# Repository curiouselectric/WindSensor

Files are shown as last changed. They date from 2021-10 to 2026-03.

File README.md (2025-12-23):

# WindSensor Overview
A DIY Wind sensor interface board.

This connects to various anemometers and wind vanes and provides a serial interface for averaged data from the pulses.

The problem with measuring wind anemometers and wind vane is that they constantly need to be checked. You need to know at all times when pulses have come in and which direction the wind vane is facing. This requires a bit of microcontroller time and processing. This unit is designed to solve that.
Wire up your vane and anemometer. Power the unit up. Then it will save the averaged data for you. You can then get hold of the data through serial requests and process as you need.

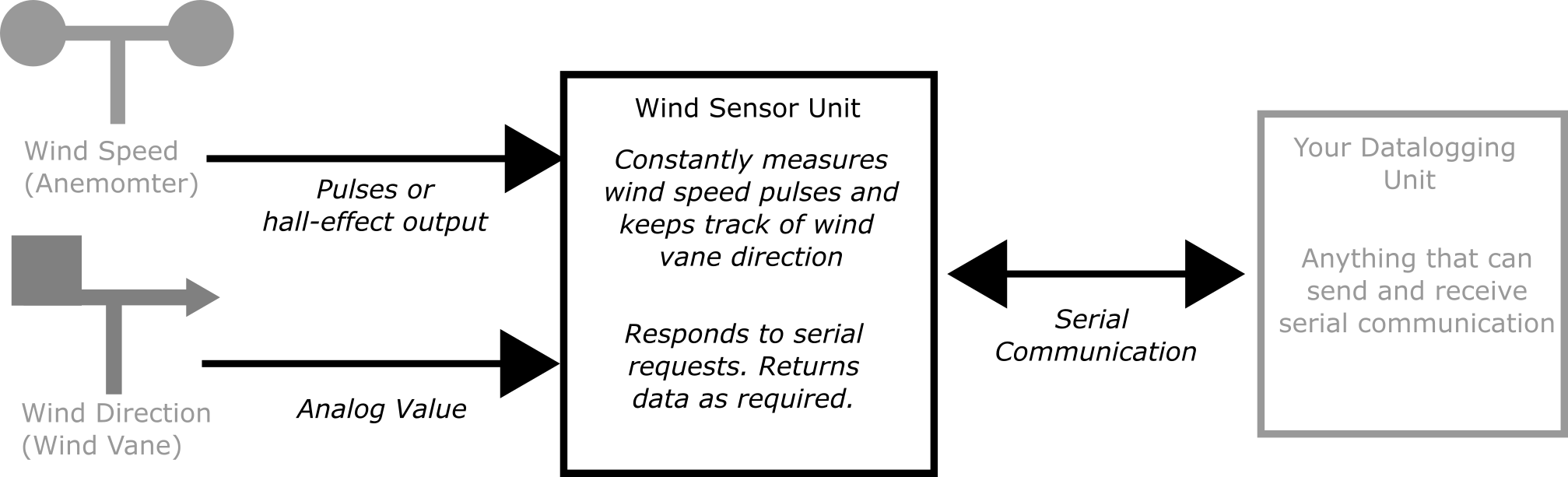
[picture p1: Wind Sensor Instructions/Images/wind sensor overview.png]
Overview


I wrote this to interface to an ESP32 data logger, which sleeps most of the time. It wakes up, talks to the wind sensor, gets the data it needs, then goes back to sleep, knowing the wind sensor is always monitoring.

It was designed as a relatively simple interface to remove the need for monitoring pulses and averaging them. 

## Wind Speed Measurements

The anemometer can either be a pulse output, NPN output or hall-effect output. The unit reads digital pulses, with circuitry on the unit converting the hall effect output to pulses. (Note: This unit cannot read 0-5V or analog output sensors).

The unit stores average wind speeds for 1 second, 10 second, 1 min, 10 min and 1 hour values. It also records the maximum and minimum wind speed.

The unit converts the pulses into a real wind speed using a y=mx+c linear conversion, where y is the wind speed and c is the number of pulses. m and c are stored in EEPROM and have default values of m=1 and c=0. These are floats and can be changed as required through the serial interface. Any updated values are stored in EEPROM. If the pulses are zero then the output is also zero (no matter what the y=mc+c function is). This stops a reading of 'c' when the pulse data is zero.

## Wind Vane Measurements

The wind vane input is analog. 

This can read either resistive wiper vanes or stepped resistive vanes. 

The stepped rsistive vanes have magnet reed switches which switch in and out different resistances. 
The resistance then tells us the direction. A pull up reistor is required in these situations.

The wind vane input can be 'trained'. So put the unit into vane training mode via the serial interface. This will run through N, NE, E, SE, S, SW, W, NW and you can hold the unit in the correct direction position and press the switch to store that data to memory. Once trained then the unit creates a buffer zone around each of the values and within the zone then the unit will record the correct direction.

Wind direction is difficult to measure, as you cannot directly average the analog value (because of the 360 to 0 point where the analog value rolls around from 1024 back to 0 - this means an average of a unit pointing just off north (i.e. one reading of 0 and one reading of 360) will give an average of (360+0)/2 = 180, which is south and totally wrong!). 

This unit will record the number of seconds the vane has been pointing in a certain direction. This means a 'wind rose' can easily be created. This is stored and updated until it is directly reset. The unit will also return the instantaeous direction, if that is needed.

Note: there is a 3V3 zener diode on the input to the Wind Vane unit. If you power the device with 3.3V then this is no problem. If you power the device with 5V then you will need to ensure the voltage at VANE does not go above 3.3V or else it will be limited.

There are two mode of operation, depending upon your use case:

## Response Mode

In this mode then the unit responds to serial requests made. You ask the sensor for data and this is returned. It never sends anything unless asked. 

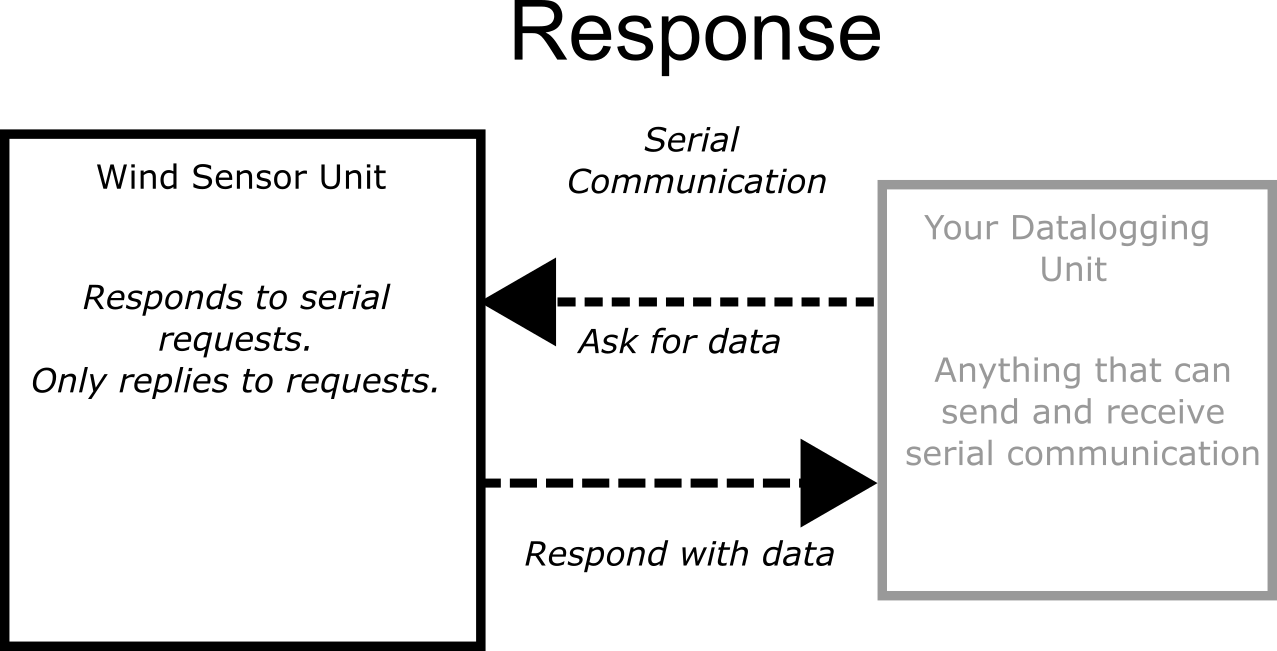
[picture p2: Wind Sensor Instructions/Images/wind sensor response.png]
Response


## Broadcast Mode

In this mode then the unit regularly sends data via the serial connunication. It will send the averaged data for (0) 1 second, (1) 10 second, (2) 1 min, (3) 10 min and (4) 1 hour averaged data. If this is set to (5) then the unit does not send any data. The send mdoe is stored in EEPROM, so it will start sending data again even if power is lost.

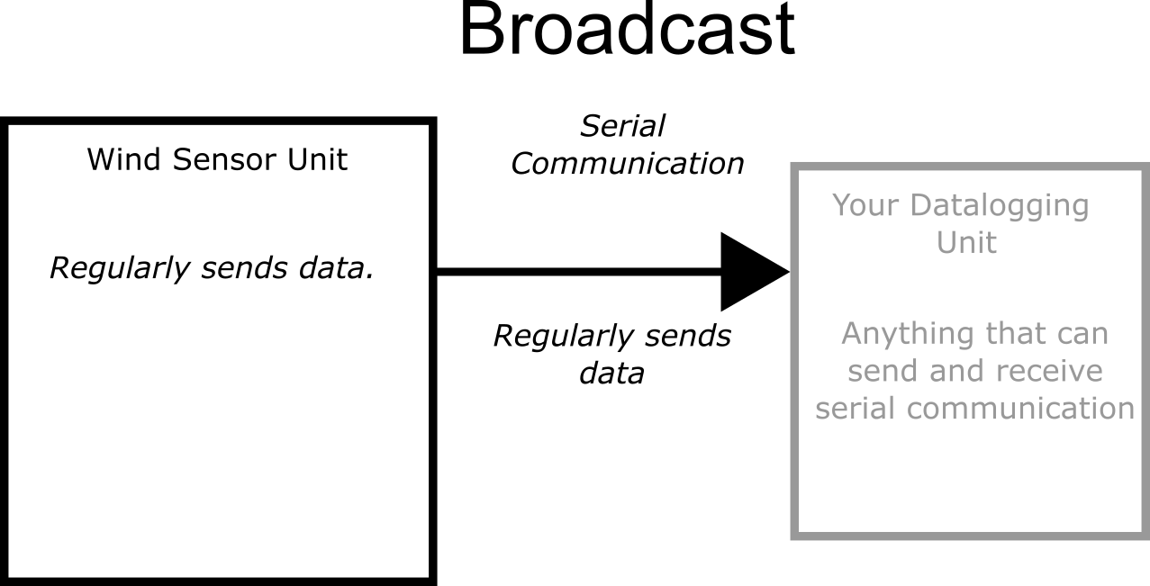
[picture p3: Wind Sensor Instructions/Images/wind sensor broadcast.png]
Broadcast


Boradcast mode works well if the logger is always listening and you only have one sensor in range. If more than one sensor is in range then the data will clash and potentially cause issues, in which case use Response mode.

The two modes work together - you can have the unit sending regular data and also responding to requests.

It runs on an ATMega328 running at 8MHz with selectable baud serial (up to 57600). It comes pre-programmed, but code can be uploaded via the Arduino IDE, using the MiniCore board add-on. See firmware for more details.

# Hardware

The PCB was designed in KiCAD and is available here. A small PCB has been designed.
There is one reset switch, one user input switch and one LED output.

Both inputs for the wind vane and anemometer are buffered with an op-amp and also have 5.1V zener protection. The anemometer input compares the input with a low voltage level to create a pulse from a hall-effect (which output a sine-wave like signal). This also works as a pull-down pulse sensor, which works with NPN and switch output anemometers.

## Anemometers Tested:

Anemometer Name      | Link   | Type   | m Value   | c Value
---------------------|----------|---------|----------|----------
Vector Insrutments NRG #40C | https://www.nrgsystems.com/products/met-sensors/detail/40c-anemometer | Hall-effect  | 0.765 for m/s | 0.35 for m/s
Maplin Anemometer (low cost) | https://www.ebay.co.uk/itm/274338314354 | Reed-switch pulse | 0.7 for m/s | 0 for m/s
AliExpress Unit (low cost) PR-3000-FS-NPN| https://www.aliexpress.com/item/32798148991.html | NPN Pulse | |

## Wind Vanes Tested:

Wind Vane Name      |   Link   |  Type
---------------------|----------|-----------
Maplin Vane | No Link |  Switched resistive

## Board ID Number

Each unit can have a unique ID (using a solder pad for 0-7 values), so multiple units can be added to a serial bus, if needed. The defalt is 0.

## PCB User Switch and User LED

There is one user switch and one user LED on the unit.

The LED will show a regular flash every 5 seconds. This will briefly flash once every 5 seconds if the unit is in 'Response' mode. The LED will briefyl flash twice every 5 seconds if the unit is in 'Broadcast' mode. Data will be sent at the broadcast rate.

The LED will also flash whenever data is sent of the serial port. The LED will go on before data sent and then off after data is sent.

Pressing the user switch for >0.5 seconds and then releasing will result in a switch press. 

A switch press will increment the mode from 0-1-2-3-4-5 then back to 0. 

The unit will flash after a button press to indicate the broadcast mode (so 0 flashes if the value is 0, 1 flash if the value is 1 etc). 

If this is set to 5 then the unit works in 'Response' mode. 

If this is set to 0-4 then the unit is in broadcast mode and will send the data at the relevant interval (0 = 1s, 1 = 10s, 2 = 1 min, 3 = 10 min and 4 = 1 hour). 

The mode can also be set with a serial request, using the "Set the unit to broadcast:" method (see below).

# Firmware
This uses an ATMega328 running at 8MHz with 3.3v or 5V supply.

## Initial bootloader installation:
You should not need to do this, as the unit should come with this already installed. This is just for information.

To upload a bootloader it then MiniCore is used:

Install MiniCore from here: https://github.com/MCUdude/MiniCore

Install the bootloader using an Arduino as an ISP. https://www.arduino.cc/en/Tutorial/BuiltInExamples/ArduinoISP

Wire up your arduino and an ISP 3x2 header pin onto the wind sensor PCB.

Choose the "ATMega328" option with the "External 8MHz Oscillator" set.

You can then use the 'Burn Bootloader' option within 'Tools' in the Arduino IDE. This will install the Minicore bootloader.

## Program via Arduino IDE

To program it then MiniCore is used:

Install MiniCore from here: https://github.com/MCUdude/MiniCore

Add to preferences and then board manager.

You can then upload code by choosing the "ATMega328" option with the "External 8MHz Oscillator" set.

# Serial Data and Commands

It returns the average values and information when requested on serial port.
At all other times then the unit is asleep.

## Wind Speed data:
Request: “aaI0WSA4#”  ("aaI0WSA4?19#" with CRC)  Where 0 is an ID from 0-7 set by solder on PCB. 4 is the averaging period (0=1s, 1=10s, 2 = 60s, 3 = 600s, 4=3600s)  

Returns: "aaI0WSA4:3.00:5.67:1.23#"  // Where 4 is the averaging period, 3.00 is the data within the averaging period, 5.67 is the maximum and 1.23 is the minimum. 
                                      
## Wind Speed data minimum:
Request: “aaI0WSMN#” ("aaI0WSMN?84#" with CRC) - does not matter what averaging period. min/max are just the min/max seen.

Returns: "aaI0WSMN:3.00#"  // Where 3.00 is the data + CRC if requested
                                      
## Wind Speed data maximum:
Request: “aaI0WSMX#”  ("aaI0WSMX?e6#" with CRC) - does not matter what averaging period. min/max are just the min/max seen.

Returns: "aaI0WSMX:3.00#"  // Where 3.00 is the data + CRC if requested

## What is Anemometer conversion?:    
Request: "aaI0WSCON#" ("aaI0WSCON?41#" with CRC)

Returns: "aaI0STWSCONm123.4c567.89#" (from stored values) + CRC if requested
                                      
## Set the Anemometer conversion:      
Request: "aaI0WSSTm123.4c567.89#"  ("aaI0WSSTm123.4c567.89?38#" with CRC) Where 123.4 is the gradient and 567.89 is the constant (y=mx+c)

Returns: "aaI0STWSSETm123.4c567.89#" (set to the new values) + CRC if requested

Request: "aaI0WSSTm1c0#" or "aaI0WSSTm1c0?da#" with CRC to set m= 1 and c=0. This is useful for initial testing.
                                      
## Wind Vane data: 
Request: “aaI0WV#”  ("aaI0WV?b4#" with CRC) Where 0 is an ID from 0-7 set by solder on PCB.

Returns:    The instantaneuous direction AND the direction array data
                                     
Returns:    "aaI0WV=W:0.00:0.00:0.00:0.00:0.00:0.00:62.00:0.00#" + CRC if requested
                                     
## Reset the max, min and wind vane array:  
Request: "aaI0RESET#" ("aaI0RESET?d9#" with CRC)

Returns: "aaRESET#"

## Set the unit to broadcast:  
Request: "aaI0SEND?#" where ? is an int (0)= 1s data, (1)= 10s data, (2)= 60s/1 min data, (3)= 600s/10 min data, (4)= 3600s/1hr data, (5)= NO data 

Returns: "aaI0SENDOK#" + CRC if requested

You can also set the unit to broadcast using the user switch. Press the button for around 0.5s or more then release. This will go through the boradcast modes from 0-1-2-3-4-5 then back round to 0. The LED will flash the number of times for the setting (so send = 0 the unit will not flash, but data will appear within 1 second!).

If the unit is in broadcast mode then the minimum and maximum wind speeds and the wind vane data are all reset each time period.

## What is baud rate?:                 
Request: "aaI0BD#" ("aaI0BD?dc#" with CRC)

Returns: "aaBD9600#"  // Where 9600 is the baud rate + CRC if requested
                                      
## Set Baud Rate:                      
Request: "aaI0STBD*#"  Where * is (0)1200, (1)2400, (2)9600, (3)57600, (4)115200

Returns: "aaBD9600#"   // Where 9600 is the baud rate + CRC if requested

## What is ID?:                        
Mentioned at start up of unit - it is solder-programmed... cannot be changed in code.

ID selection is by using a blob of solder to connect together some pads labelled A0, A1 and A2. The default is for no pads to be soldered and the ID is 0. This means the unit will respond to "I0" as the ID.

To change the ID to another number from 0-7 then we can solder the different connection pads to create a binay number. The connections are:

A0     |A1     |A2     | ID
-------|-------|-------|----
NC     |NC     |NC     | 0
Solder |NC     |NC     | 1
NC     |Solder |NC     | 2
Solder |Solder |NC     | 3
NC     |NC     |Solder | 4
Solder |NC     |Solder | 5
NC     |Solder |Solder | 6
Solder |Solder |Solder | 7

## Enter vane training mode:           
Request: "aaI0VT#" ("aaI0VT?af#" with CRC)

Returns: Enter the vane training routine - use button to go through the different directions and set the values.

The serial port will show which direction the vane should be pointing at. 

Move the vane to this position and press the user switch (for around 0.5 seconds).

The serial port will show then next direction and will got N, NE, E, SE, S, SW, W, NW and then end.

The unit will also send "aaI0WVOK=NW" + CRC +"#" to report back which direction the unit is now being trained.

When it ends this data is stored within the unit and the direction 'bands' are recaluclated.

## Serial 'Button' press

The command "aaI0BUTTON" + CRC + "#" will act just like a button press. This is for control via a data logger serial port without access to the physical switch.

## Add CRC check:           
Within the config of the firmware a CRC (Cyclic Redundancy Check) can be added to the data (or not!).

Set this true using the flag in the config.h file:

  #define ADD_CRC_CHECK     true    // Use this to add CRC check to incomming and outgoing messages

This uses the CRC routines from Rob Tillaart, available here: https://github.com/RobTillaart/CRC

A 'CRC-8/SMBUS' is perfromed on the data and a 2 byte CRC code is added to all replys (and expected on all enquiries). This is added between a ? and # symbol.

If no CRC then the end char is a #.

For example: aaI0RESET?d9# has the CRC check d9 added to the reset request.

Remember: Capitalisation will affect the results: D is not the same as d!

You can use this online calculator to check your CRC: https://crccalc.com/ The type of CRC is CRC-8/SMBUS.

## Failure codes:
If data is not that length or does not have 'aa' and '#' at start/end then return with send "aaFAIL**#" error code. All will have CRC on these codes, if requested.

"aaFAIL1#" = String too long

"aaFAIL2#" = Unit ID not correct/not a number

"aaFAIL3#" = Channel ID is not correct/not a number

"aaFAIL4#" = Average not correct/not a number

"aaFAIL5#" = Start/End chars not correct

# Overview of Connections

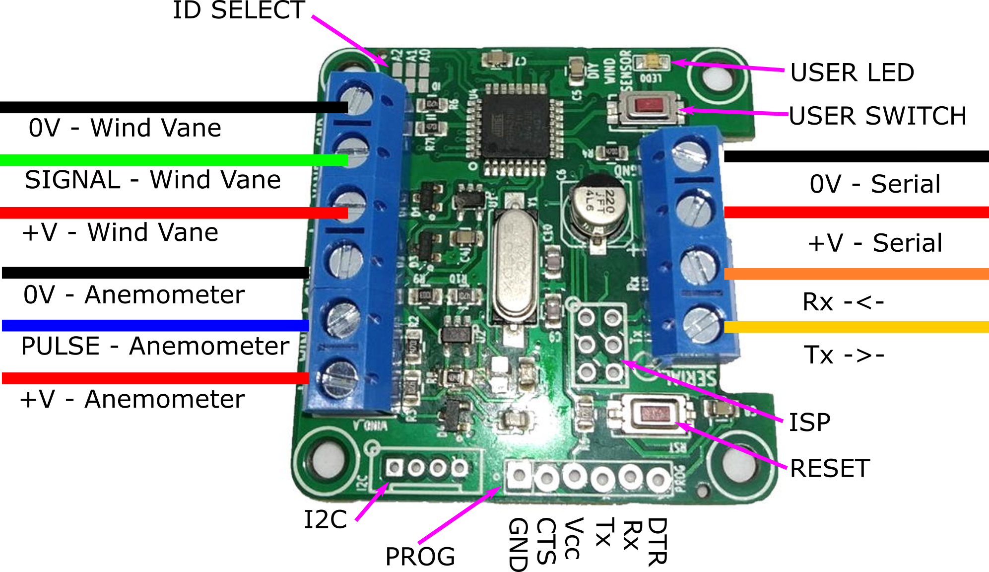
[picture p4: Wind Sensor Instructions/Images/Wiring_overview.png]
Connections


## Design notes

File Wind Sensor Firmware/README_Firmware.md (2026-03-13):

# WindSensor Firmware

The firmware for this project has been moved to: 

[https://github.com/curiouselectric/SensorInterfaceBoard/tree/main/Sensor%20Interface%20Board%20Firmware](https://github.com/curiouselectric/SensorInterfaceBoard/tree/main/Sensor%20Interface%20Board%20Firmware)

This is within the Sensor Interface Board repository: [https://github.com/curiouselectric/SensorInterfaceBoard](https://github.com/curiouselectric/SensorInterfaceBoard)

I have done this to keep all the sensor boards up to date with just one set of firmware for all the sensor boards.

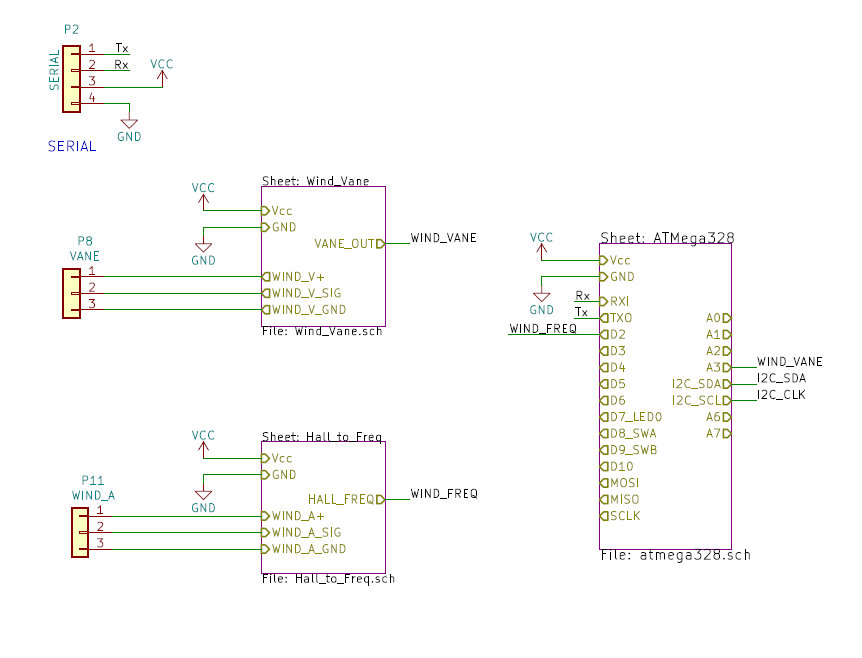
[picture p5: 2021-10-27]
Wind Sensor PCB/SVG/Schematic_Overview.PNG

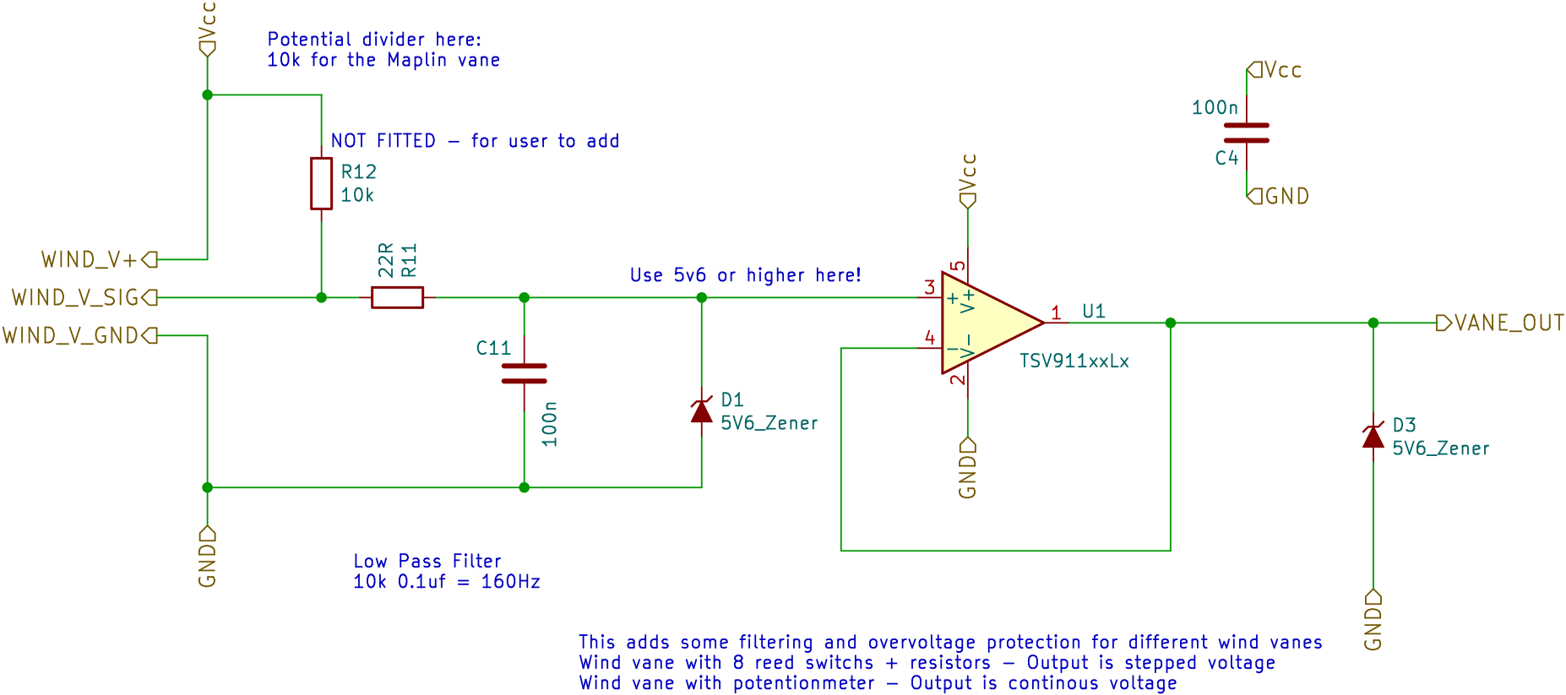
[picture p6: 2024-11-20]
Wind Sensor PCB/SVG/Schematic_2.PNG.png

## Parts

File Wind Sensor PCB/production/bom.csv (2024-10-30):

Designator | Footprint | Quantity | Value | LCSC Part #
C1, C11, C3, C4, C5, C7, C8 | SM_C_0805 | 7 | 100n | C49678
C10, C9 | SM_C_0805 | 2 | 22p | C1804
C2 | SM_C_0805 | 1 | 22n | C1729
C6 | SM_6.3x7.7 | 1 | 100u | C164071
D1, D4 | SOT23_ZENER | 2 | 3V3_Zener | C493206
D2 | SM0805_LED | 1 | LED0 | C2296
D3 | SOT23_ZENER | 1 | 5V1_Zener | C131770
R1, R10, R11, R5 | SM0805 | 4 | 10k | C17414
R2, R3 | SM0805 | 2 | 4k7 | C17673
R4 | SM0805 | 1 | 470 | C17710
R6, R7 | SM0805 | 2 | 4k7 | C17673
R8 | SM0805 | 1 | 470k | C17709
R9 | SM0805 | 1 | 100k | C149504
SW1 | SMD_SW_6x3_5 | 1 | SWA | C412368
SW2 | SMD_SW_6x3_5 | 1 | RST | C412368
U1, U2 | SM_SOT-23-5 | 2 | TSV911xxLx | C361052
U4 | TQFP32-08 | 1 | ATmega328P-AU | C14877
Y1 | SM-crystal-HC49UP | 1 | 8MHz_XTAL | C12674

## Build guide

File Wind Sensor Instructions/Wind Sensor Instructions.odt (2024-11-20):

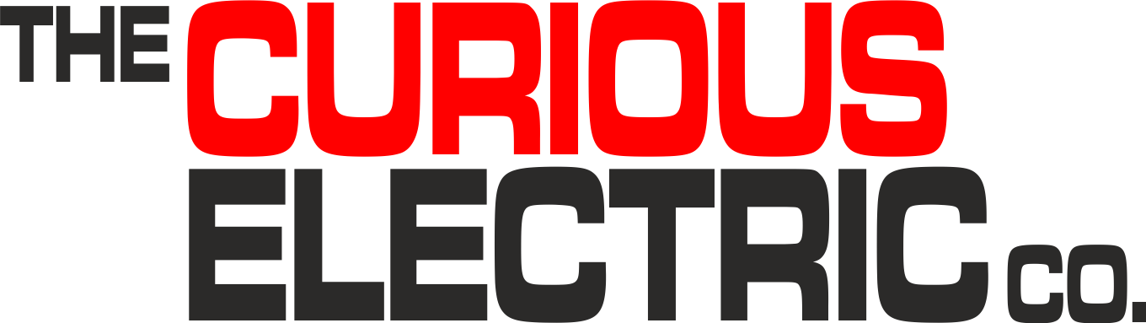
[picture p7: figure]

| Wind Sensor Instructions

Date: | 20/11/24 | Version: | 1.1 | By: | Matt Little

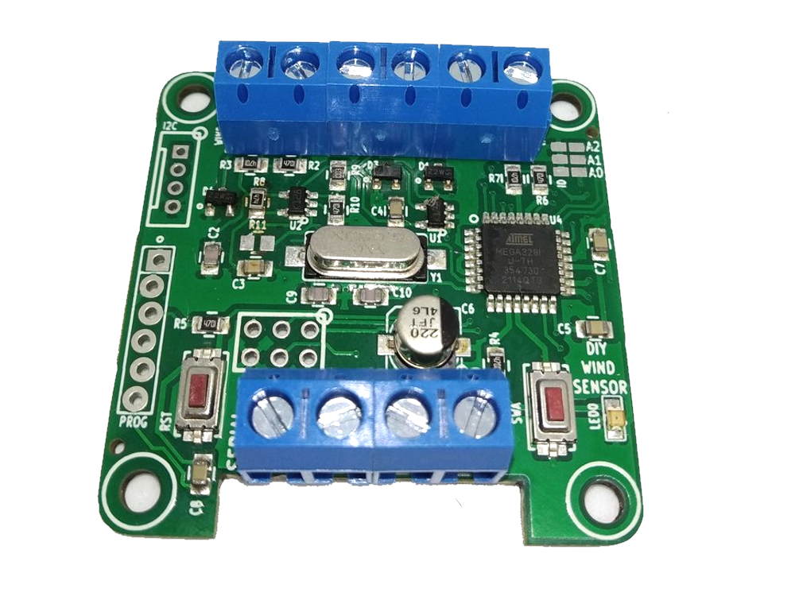
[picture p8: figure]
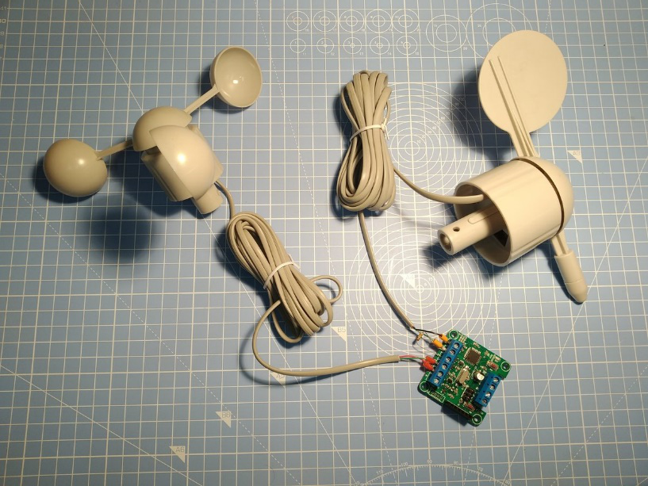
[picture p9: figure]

This connects to various anemometers and wind vanes and provides a serial interface for averaged data from the pulses.

The problem with measuring wind anemometers and wind vane is that they constantly need to be checked. You need to always know when pulses have come in and which direction the wind vane is facing. This requires a bit of microcontroller time and processing.

This unit is designed to solve that. Wire up your vane and anemometer. Power the unit up. Then it will save the averaged data for you. You can then get hold of the data through serial requests and process as you need.

This unit can be ‘trained’ for your Wind Vane and the pulses converted into a real wind speed with a “Y = mX + c” conversion. The conversion values (m and c) can be adjusted for your anemometer.

All the firmware, unit operation and serial commands can be found here:

https://github.com/curiouselectric/WindSensor

# Parts included:

| | | 5 x 2 way Screw Terminals

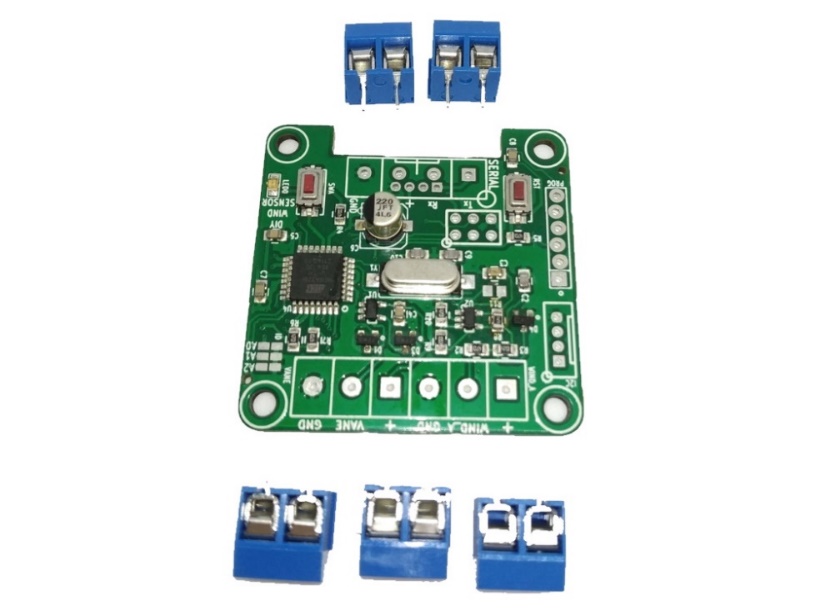
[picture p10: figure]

| | | | PCB with SMD components

# Parts list:

Item | Ref | Quantity
2 way screw terminals | | 5
PCB with all SMD components soldered | | 1

# Tools required:

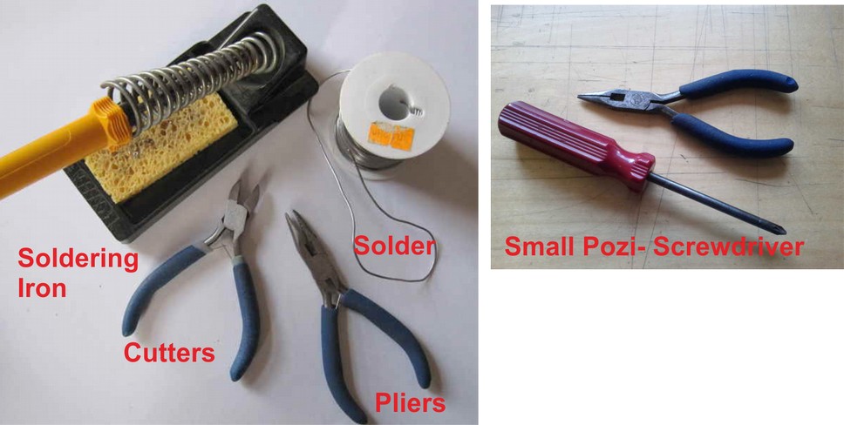
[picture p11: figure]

| | Long-nosed Pliers
Soldering Iron | | Posi-drive Screwdriver
Solder
Side cutters

Additional Items

- USB to 6 way ‘FTDI’ style serial converter:
  - Search for “FT232RL USB to TTL MiniUSB Port FTDI Serial Adapter Module for Arduino 5V 3.3V” on eBay
  - Or this FTDI one: https://ftdichip.com/products/ttl-232r-3v3/
  - You can also use an Arduino as a USB to serial converter.
- To update/change code: Computer with Arduino IDE and additional libraries installed. (see software section for more details).

Instructions:

Step: 1 | Solder Screw Terminals

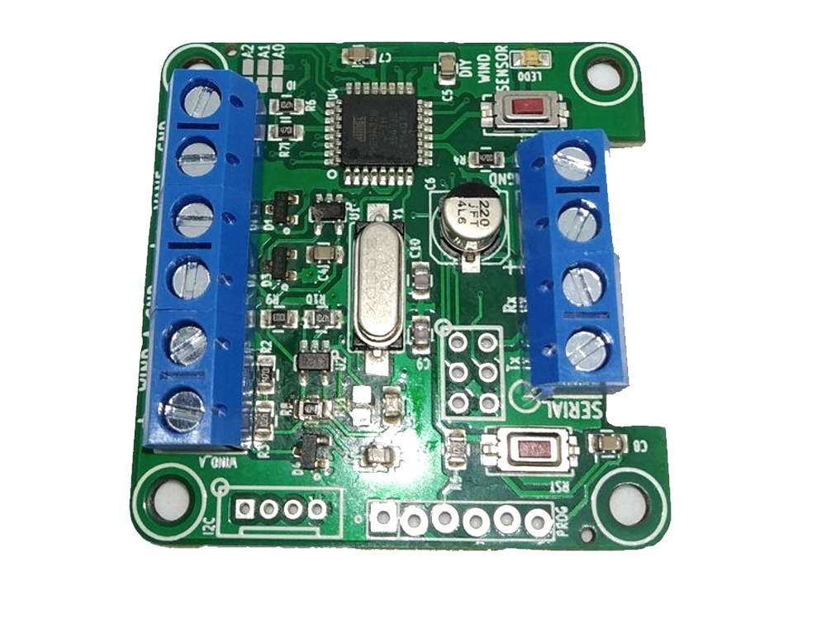
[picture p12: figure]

There are 5 2 way screw terminals to solder. Link two of them to make a 4 way connector and solder into the ‘serial’ connection. Link three of them and solder into the WIND_A and VANE connections, as shown. That’s all the soldering done!

Step: 2 | Set ID

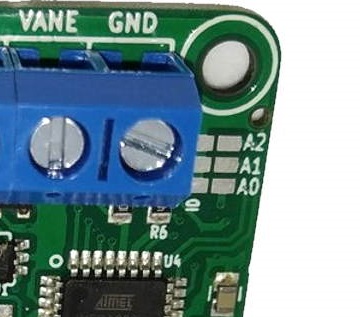
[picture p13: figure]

This step is not usually required. You can set the ID of the unit by connecting some pads with a solder blob. Solder according to this table. “Solder” means connect the two pads, “NC” means no connection. The default is 0. A0 A1 A2 ID NC NC NC 0 Solder NC NC 1 NC Solder NC 2 Solder Solder NC 3 NC NC Solder 4 Solder NC Solder 5 NC Solder Solder 6 Solder Solder Solder 7

Step: 3 | Wire up Anemometer

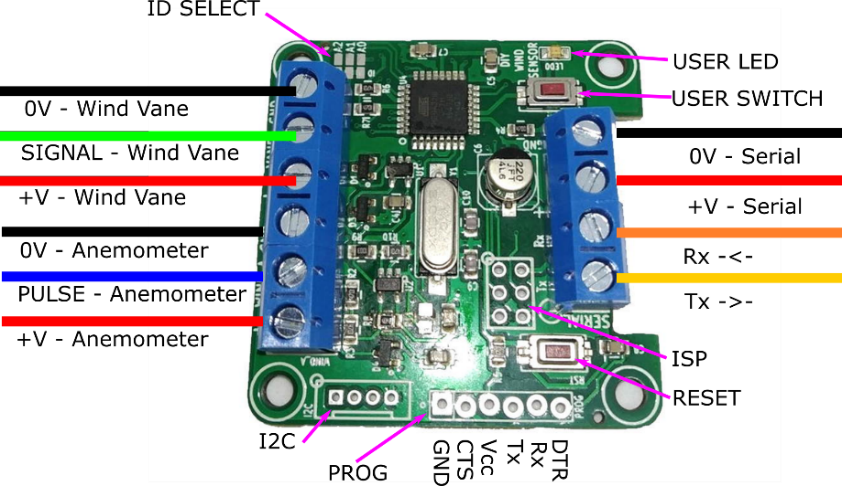
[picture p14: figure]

Wiring for this depends upon the type of anemometer: For switched pulse anemometers: connect the switch to 0V and to PULSE input, as there is a pull-up resistor. For NPN output anemometers: The +V will supply the Vcc to your anemometer. Typically, this is 3.3V or 5V. Wire this to the +ve of your anemometer. 0V is ground. Wire the NPN pulse output to PULSE. For Hall-Effect anemometers: Connect the output to the 0V and the PULSE input.

Step: 4 | Wire up Wind Vane

The wind vane wiring will also be different depending upon the type of vane.

For a resistive switched output vane, then you will need to use a 10k or 100k pull up resistor. Wire the vane output to 0V and SIGNAL. You can then either wire an external pull-up resistor to SIGNAL and +5V OR you can add a surface mount 0805-sized resistor onto the empty pad R12.

R12/pull-up resistor is simply a pull up resistor to the +V line, so choose the value according to your vane (typically 10k or 100k).

For potentiometer output vanes wire the 0V to one side of the variable resistor and the +5V for the other side of the variable resistor. The wire the wiper to SIGNAL.

Basically, you are trying to make a variable voltage input for the SIGNAL input.

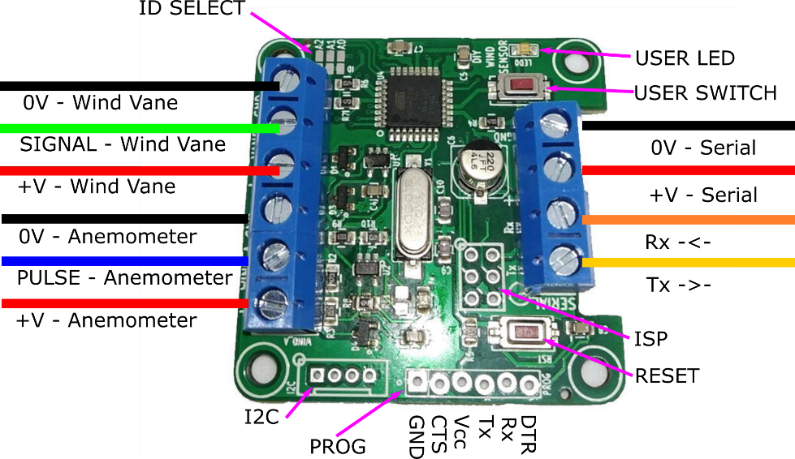
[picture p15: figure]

Step: 5 | PCB is finished!

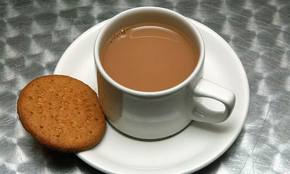
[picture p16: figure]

Have a nice cup of tea. | | That didn’t take long, did it?

Step: 6 | Connect to Arduino or USB-Serial Converter

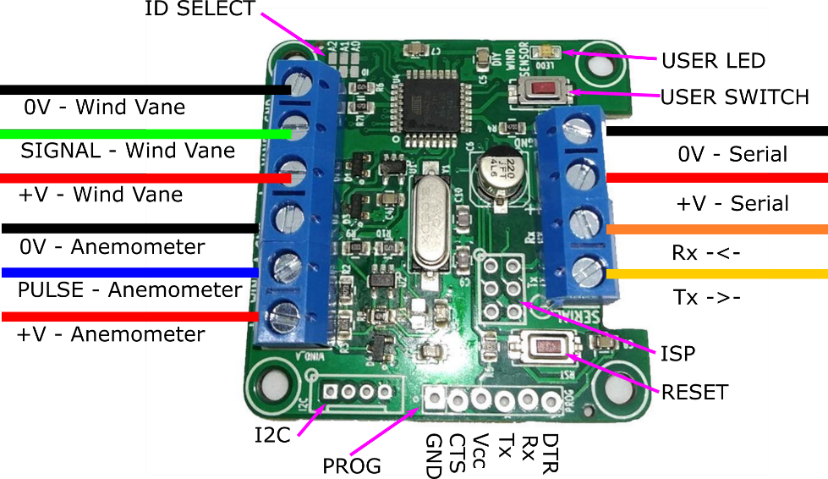
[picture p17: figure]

There is one main serial connector which has 0V, +V for the serial and also Rx and Tx. Upload a blank or ‘bare minimum’ sketch to an Arduino. You can wire your Arduino Tx to Rx and Rx to Tx. If you monitor the serial port at 9600 baud then you can send and receive responses. Follow the github examples and information for the most up to date information regarding the serial data and the functionality of the unit.

Step: 7 | Send Serial Commands
There are many serial commands that the unit can respond to. Please see: https://github.com/curiouselectric/WindSensor For the most recent information. This is kept online, so it can be easily updated.

Step: 8 | Write your own code
Everyone’s application is different, so this is where things get fun for your application! You need to think about what you would like from the unit. I have set up units that send out data at regular 1min outputs with a wireless transmitter. This used broadcast mode. I have also set up units that record the data to an SD card by using request mode.

Upload Firmware

This is not needed for standard use of the unit.

This can be where the fun begins! You can alter the code and improve it as you need.

This project has software stored on GITHUB software repository here:

https://github.com/curiouselectric/WindSensor

Please follow the readme in this repository for the most up to date instructions.

## Contact details:

This kit has been designed and produced by:

The Curious Electric Company

hello@curiouselectric.co.uk

www.curiouselectric.co.uk

We would like you to be happy with this kit. If you are not happy for any reason, then please contact us and we will help to sort it out.

Please email hello@curiouselectric.co.uk with any questions or comments.

Please tweet us at @curiouselectric

If any parts are missing from your kit, then please email hello@curiouselectric.co.uk with details, including when and where the kit was purchased.

More technical information can be found via www.curiouselectric.co.uk

# Circuit Schematic:

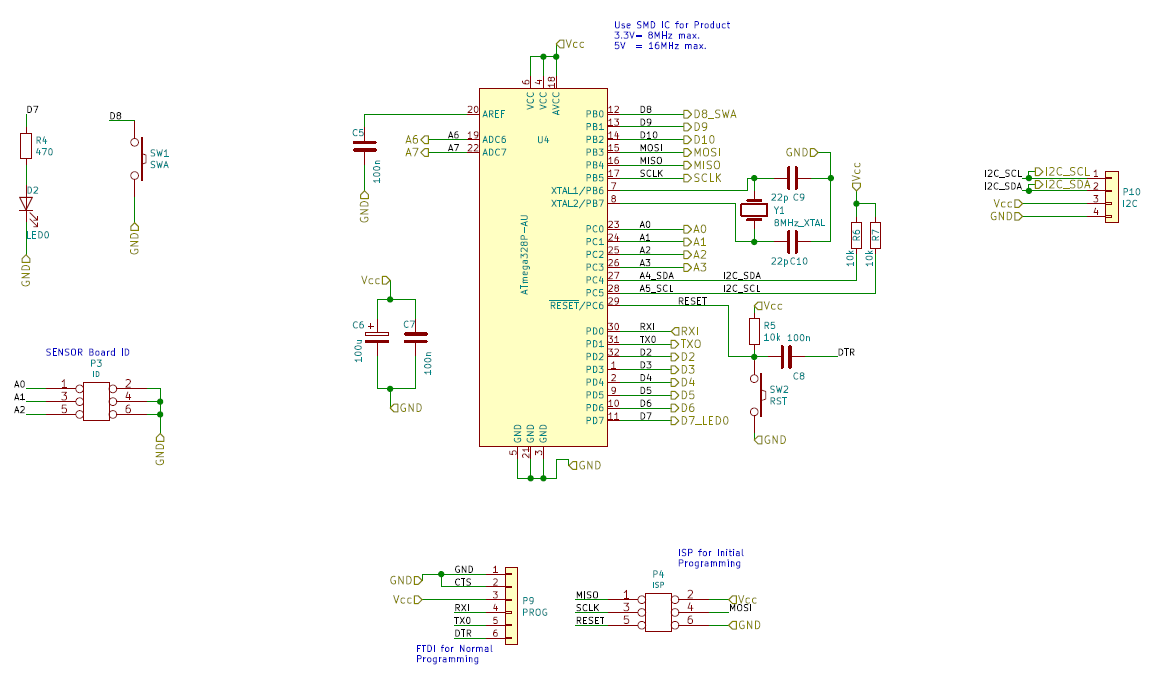
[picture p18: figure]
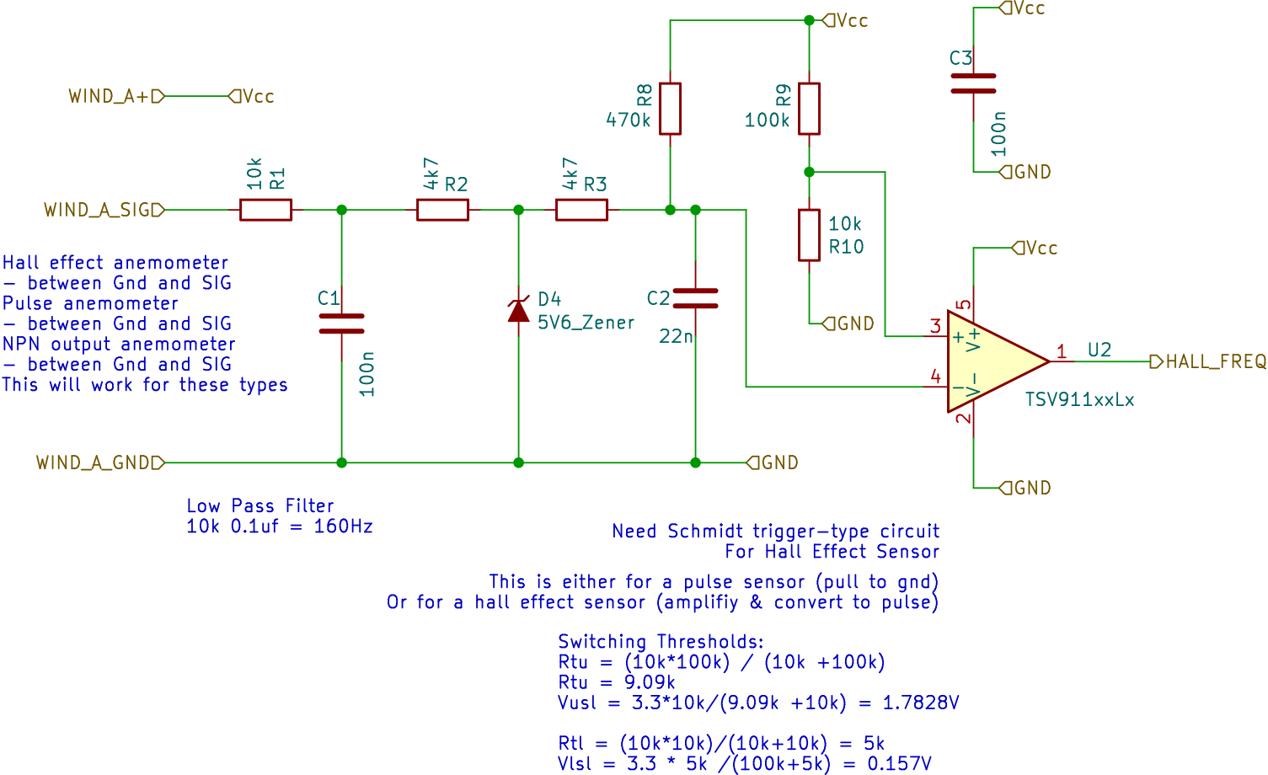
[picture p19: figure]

# PCB Design:

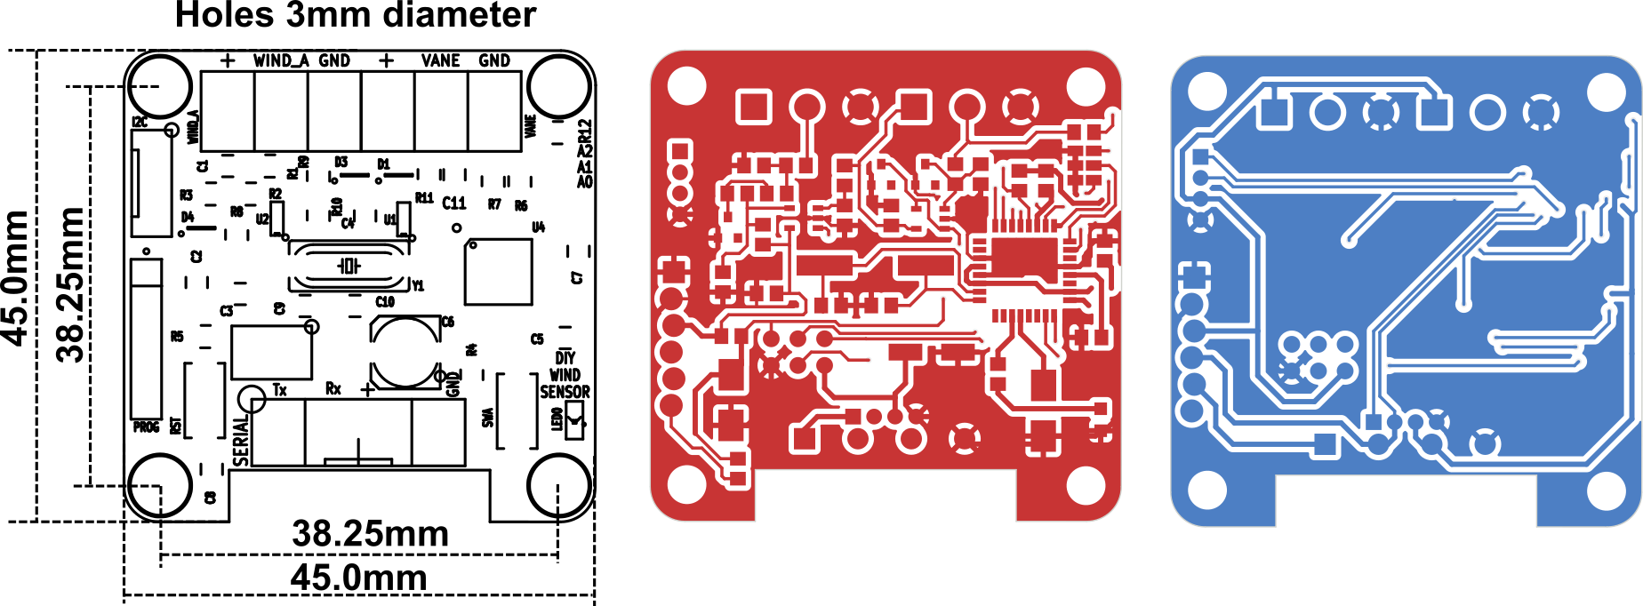
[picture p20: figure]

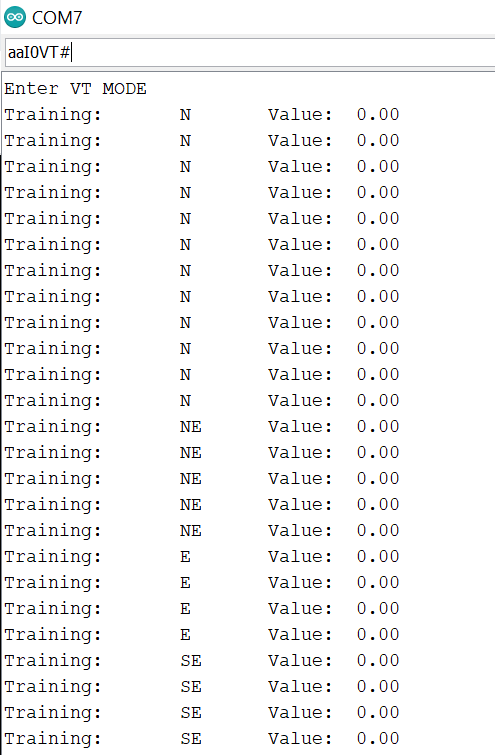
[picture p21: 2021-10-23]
Wind Sensor Instructions/Images/WS_3.PNG

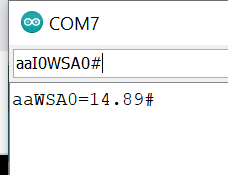
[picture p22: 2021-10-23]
Wind Sensor Instructions/Images/WS_1.PNG

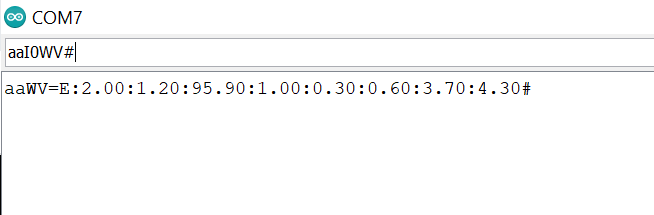
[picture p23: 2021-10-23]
Wind Sensor Instructions/Images/WS_2.PNG

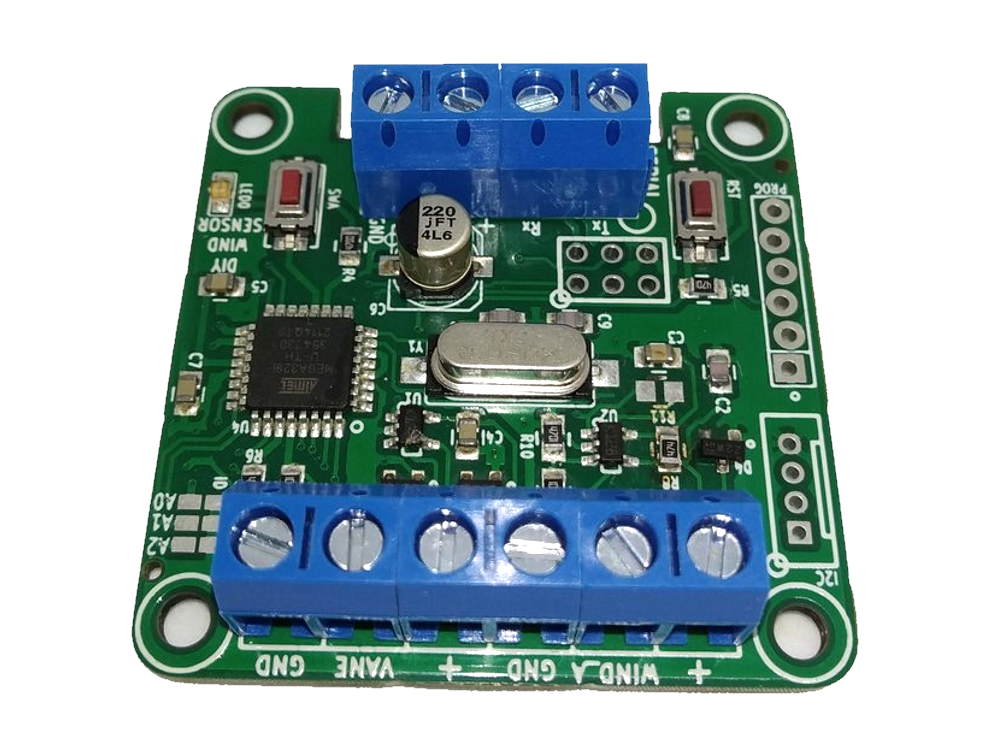
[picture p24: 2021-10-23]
Wind Sensor Instructions/Images/wind_sensor_3.jpg

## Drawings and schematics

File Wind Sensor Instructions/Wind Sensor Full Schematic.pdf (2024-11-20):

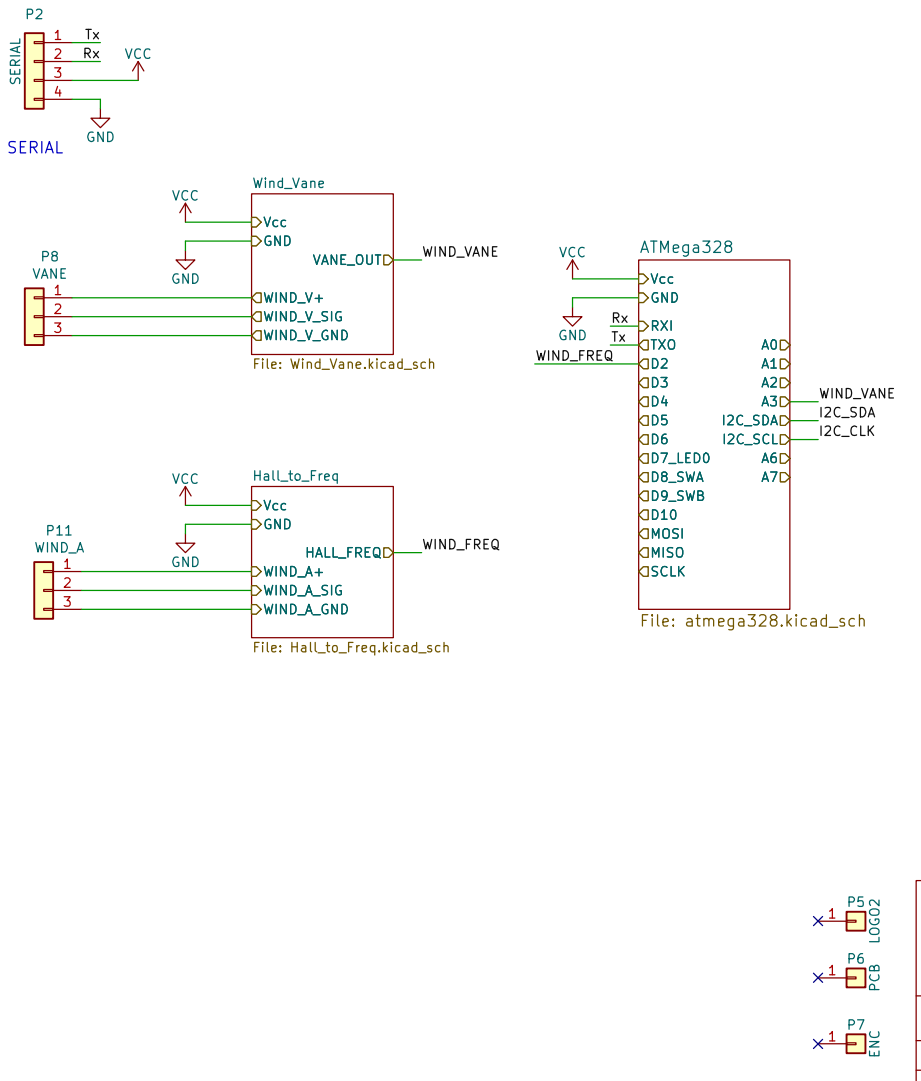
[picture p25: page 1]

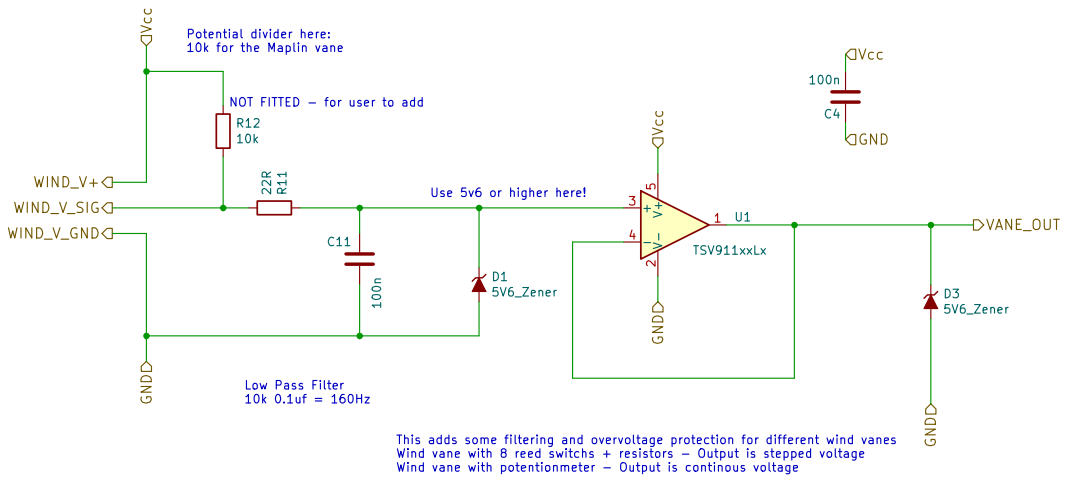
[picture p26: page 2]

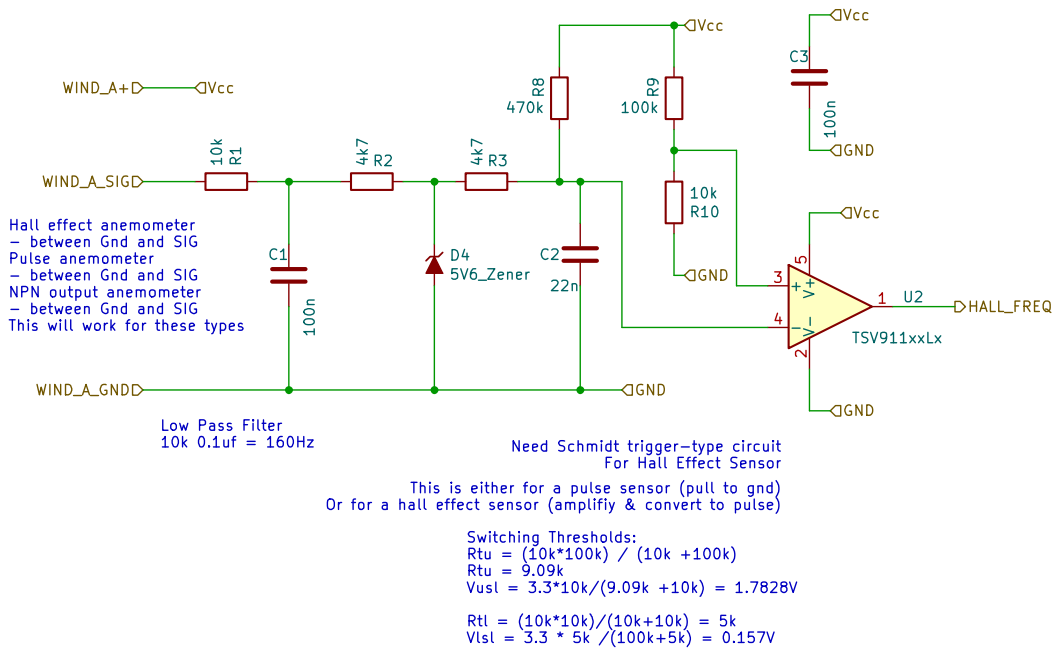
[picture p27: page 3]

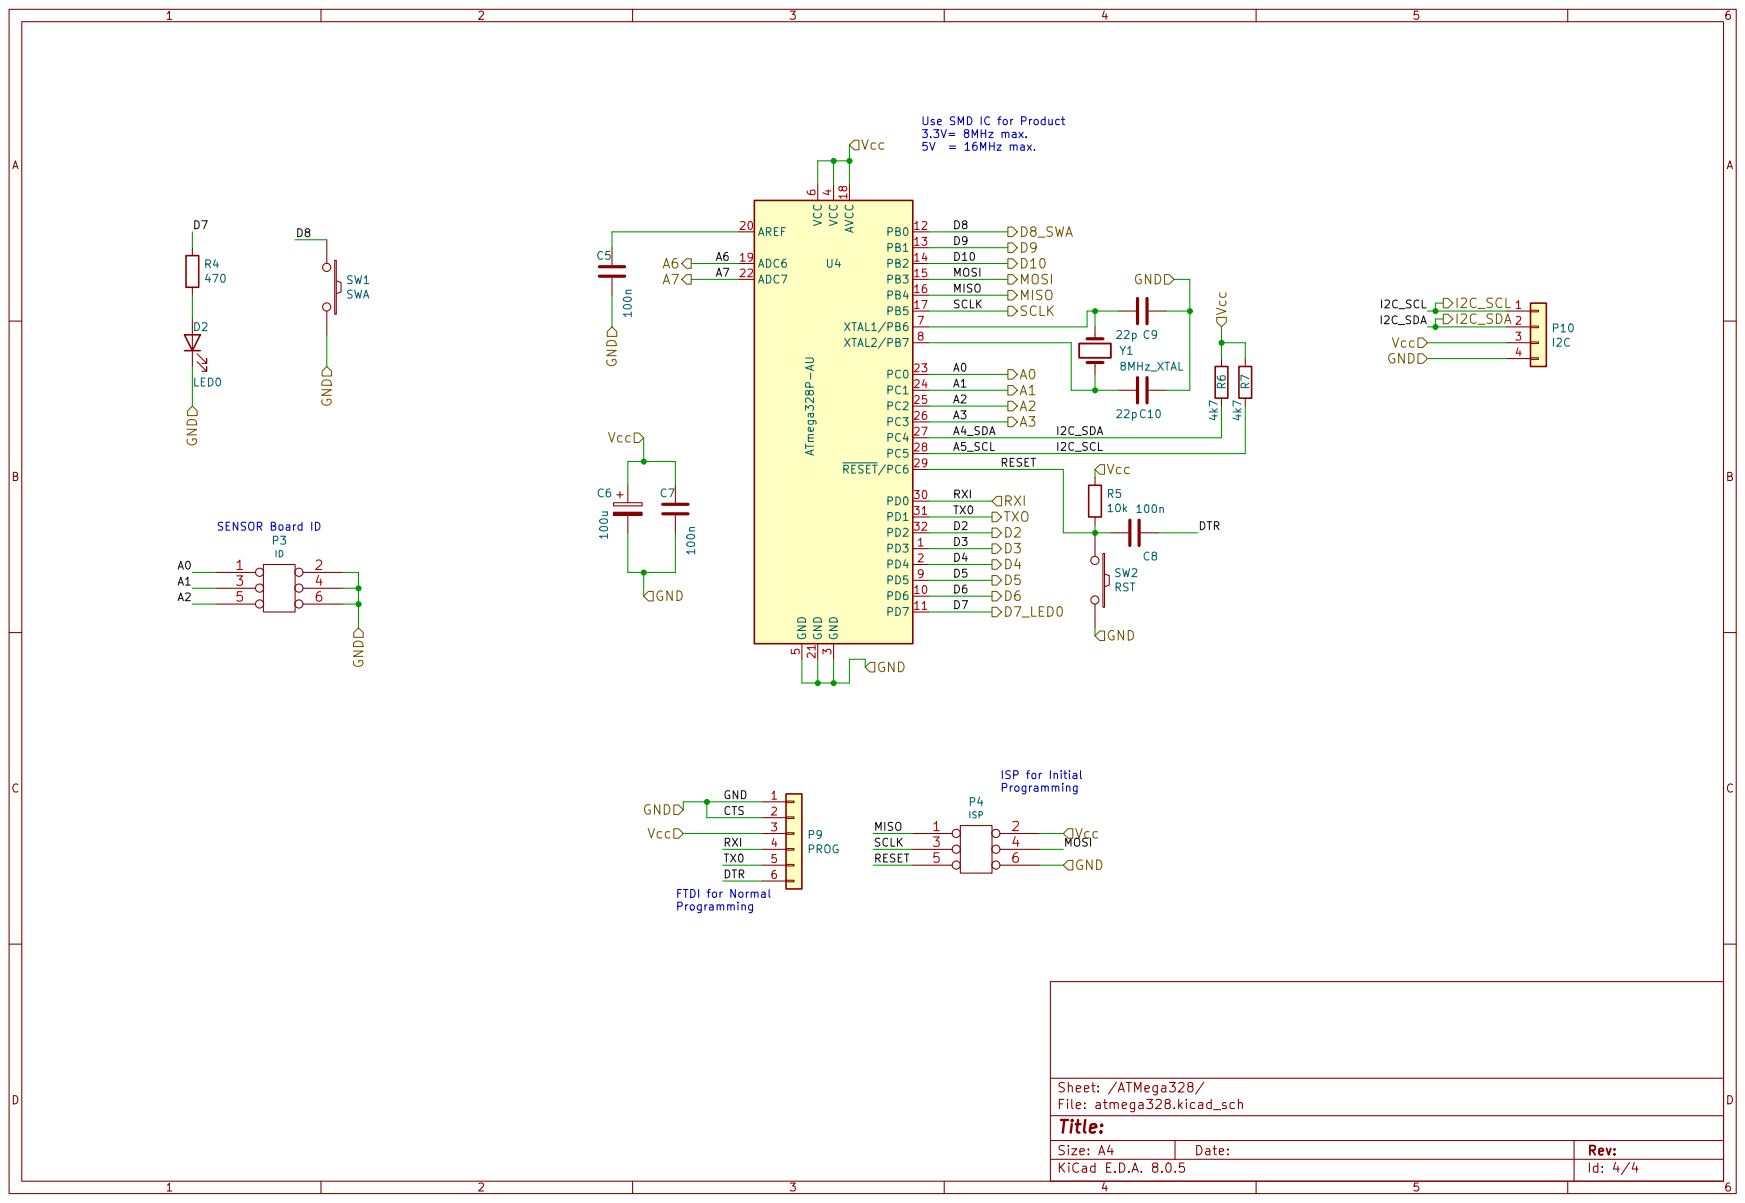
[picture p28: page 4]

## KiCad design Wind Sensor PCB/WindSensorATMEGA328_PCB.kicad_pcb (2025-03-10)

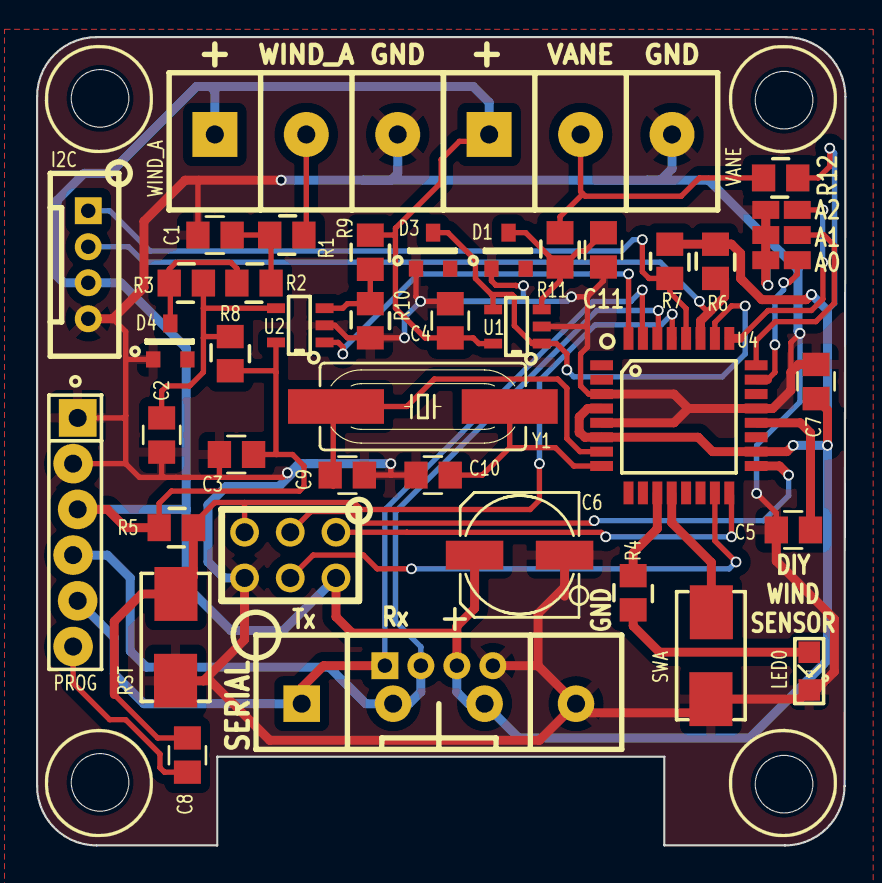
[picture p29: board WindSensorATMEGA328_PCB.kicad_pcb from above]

Board: 2 copper layers, 44.9 x 44.9 mm, 42 parts (1 on the bottom side), 29 nets.

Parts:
C1, C3, C4, C5, C7, C8, C11: 100n; SM_C_0805
C2: 22n; SM_C_0805
C6: 100u; SM_6.3x7.7
C9, C10: 22p; SM_C_0805
D1, D4: 3V3_Zener; SOT23_ZENER
D2: LED0; SM0805_LED
D3: 5V1_Zener; SOT23_ZENER
P2: SERIAL; SIL-4_Grove_SCREW
P3: ID; SM_6pad_3W_SOLDER
P4: ISP; ISP_3x2
P5: LOGO2; TCEC_Words_13mm
P6: PCB; PCB_45_45_Cut_Out_Solar_Sensor_2
P8: VANE; SIL-3_screw_terminal
P9: PROG; TH_6x1_FTDI
P10: I2C; SIL-4_Grove_Not_Labelled
P11: WIND_A; SIL-3_screw_terminal
R1, R5, R10, R11, R12: 10k; SM0805
R2, R3, R6, R7: 4k7; SM0805
R4: 470; SM0805
R8: 470k; SM0805
R9: 100k; SM0805
SW1: SWA; SMD_SW_6x3_5
SW2: RST; SMD_SW_6x3_5
U1, U2: TSV911xxLx; SM_SOT-23-5
U4: ATmega328P-AU; TQFP32-08
Y1: 8MHz_XTAL; SM-crystal-HC49UP

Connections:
/ATMega328/A0: P3.1, U4.23 (PC0)
/ATMega328/A1: P3.3, U4.24 (PC1)
/ATMega328/A2: P3.5, U4.25 (PC2)
/ATMega328/D7: R4.1, U4.11 (PD7)
/ATMega328/D8: SW1.1, U4.12 (PB0)
/ATMega328/DTR: C8.1, P9.6
/ATMega328/MISO: P4.1, U4.16 (PB4)
/ATMega328/MOSI: P4.4, U4.15 (PB3)
/ATMega328/RESET: C8.2, P4.5, R5.2, SW2.1, U4.29 (~RESET/PC6)
/ATMega328/SCLK: P4.3, U4.17 (PB5)
/Hall_to_Freq/WIND_A_SIG: P11.2, R1.2
/I2C_CLK: P10.1, R7.2, U4.28 (PC5)
/I2C_SDA: P10.2, R6.2, U4.27 (PC4)
/Rx: P2.2, P9.4, U4.30 (PD0)
/Tx: P2.1, P9.5, U4.31 (PD1)
/WIND_FREQ: U2.1, U4.32 (PD2)
/WIND_VANE: D3.2 (K), U1.1, U1.4 (-), U4.26 (PC3)
/Wind_Vane/WIND_V_SIG: P8.2, R11.2, R12.2
GND: C1.1, C2.2, C3.1, C4.1, C5.1, C6.2, C7.1, C9.1, C10.1, C11.1, D1.1 (A), D2.1 (K), D3.1 (A), D4.1 (A), P2.4, P3.2, P3.4, P3.6, P4.6, P8.3, P9.1, P9.2, P10.4, P11.3, R10.1, SW1.2, SW2.2, U1.2 (V-), U2.2 (V-), U4.3 (GND), U4.5 (GND), U4.21 (GND)
unnamed: C1.2, R1.1, R2.2
unnamed: C11.2, D1.2 (K), R11.1, U1.3 (+)
unnamed: D2.2 (A), R4.2
unnamed: D4.2 (K), R2.1, R3.2
unnamed: R9.2, R10.2, U2.3 (+)
unnamed: C2.1, R3.1, R8.2, U2.4 (-)
unnamed: C5.2, U4.20 (AREF)
unnamed: C9.2, U4.7 (XTAL1/PB6), Y1.1
unnamed: C10.2, U4.8 (XTAL2/PB7), Y1.2
VCC: C3.2, C4.2, C6.1, C7.2, P2.3, P4.2, P8.1, P9.3, P10.3, P11.1, R5.1, R6.1, R7.1, R8.1, R9.1, R12.1, U1.5 (V+), U2.5 (V+), U4.4 (VCC), U4.6 (VCC), U4.18 (AVCC)

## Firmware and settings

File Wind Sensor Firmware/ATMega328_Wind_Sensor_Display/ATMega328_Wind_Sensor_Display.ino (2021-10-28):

/*
   Wind Sensor Display firmware for ATMega328
   by:    Matt Little
   date:  27/10/2021
   w:     www.curiouselectric.co.uk
   e:     hello@curiouselectric.co.uk

   This code is for an ATMega328 unit solar sensor unit.
   This uses an ATMega328 running at 8MHz with 3.3v or 5V supply.

    This version outputs the wind data onto an OLED screen.
    It is paired down from the usual design, to give enough memory for the OLED screen

   It returns the average values when requested on serial port.
   Or it broadcasts wind speed and direction data at set intervals.
   At all other times then the unit is asleep.



   More construction details are here:
   https://github.com/curiouselectric/WindSensor

   Details on this construction are here:
   https://www.re-innovation.co.uk/docs/anemometer-monitor-for-wind-measurements/

   Please see the github rpository readme for all the serial commands available.

   To program it then MiniCore is used:
   // For optiboot using 3.3V and 8MHz and with WDT we need to sort out new code:
   Easiest method is:
   Install MiniCore from here: https://github.com/MCUdude/MiniCore
   Add to preferences and then board manager.

   Use minicore to burn the bootloader with an Arduino as an ISP using the 'Burn Bootloader' option

  Optiboot can also be used as the bootlloader:
  Need to download optiboot5a from here:
  https://code.google.com/archive/p/optiboot/downloads
  Install optiboot_atmega328.hex into a folder called "optiboot5a" in the hardware section
  Use this optiboot hex file for upload to the ATmega328
  Fuses are: Low = 0xFF, High = 0xDE, Extended = 0xFE

  Based on:
  http://www.arduino.cc/en/Tutorial/SerialEvent

*/

#include <stdio.h>
#include <Arduino.h>

#include <EEPROM.h>       // for saving mode to EEPROM
#include <avr/wdt.h>      // for the watch dog timer

#include <U8x8lib.h>

#include "Button2.h"      // Need to include this to the library
#include "config.h"
#include "serial_parse.h"
#include "anemometer_data.h"
#include "utilitiesDL.h"
#include "PulseCounter.h"
#include "wind_vane.h"

U8X8_SSD1306_128X64_NONAME_SW_I2C u8x8(/* clock=*/ SCL, /* data=*/ SDA, /* reset=*/ U8X8_PIN_NONE);   // OLEDs without Reset of the Display

// ****** This is for the buttons button2 library used and needs to be installed ********
// https://github.com/LennartHennigs/Button2
Button2 buttonA = Button2(SWA_PIN);

int SERIAL_BAUD;
long int baud_rates[MAX_BAUD_RATES] = {1200, 4800, 9600, 57600, 115200}; // This holds the available baud rates

// ******** This is for Scheduling Tasks **************************
// Must include this library from Arduino IDE Library Manager
// https://github.com/arkhipenko/TaskScheduler
#include <TaskScheduler.h>

// #define _TASK_TIMECRITICAL      // Enable monitoring scheduling overruns
#define _TASK_SLEEP_ON_IDLE_RUN    // Enable 1 ms SLEEP_IDLE powerdowns between tasks if no callback methods were invoked during the pass
// #define _TASK_STATUS_REQUEST    // Compile with support for StatusRequest functionality - triggering tasks on status change events in addition to time only
// #define _TASK_WDT_IDS           // Compile with support for wdt control points and task ids
// #define _TASK_LTS_POINTER       // Compile with support for local task storage pointer
// #define _TASK_PRIORITY          // Support for layered scheduling priority
// #define _TASK_MICRO_RES         // Support for microsecond resolution
// #define _TASK_STD_FUNCTION      // Support for std::function (ESP8266 and ESP32 ONLY)
// #define _TASK_DEBUG             // Make all methods and variables public for debug purposes
// #define _TASK_INLINE            // Make all methods "inline" - needed to support some multi-tab, multi-file implementations
// #define _TASK_TIMEOUT           // Support for overall task timeout
// #define _TASK_OO_CALLBACKS      // Support for dynamic callback method binding
// #define _TASK_DEFINE_MILLIS     // Force forward declaration of millis() and micros() "C" style
// #define _TASK_EXPOSE_CHAIN      // Methods to access tasks in the task chain

// Callback methods prototypes
void t1Callback();
void t1SCallback();
void t10SCallback();
void t60SCallback();
void t600SCallback();

// Tasks
// time (mS) between tasks, number of tasks to do, call back function
/*
  Scheduling defines:
  TASK_MILLISECOND
  TASK_SECOND
  TASK_MINUTE
  TASK_HOUR
  TASK_IMMEDIATE
  TASK_FOREVER
  TASK_ONCE
  TASK_NOTIMEOUT
*/

Task t1     (100 * TASK_MILLISECOND, TASK_FOREVER,  &t1Callback);   // Sample as base rate of 10Hz
Task t1S    (TASK_SECOND, TASK_FOREVER, &t1SCallback);
Task t10S   (10 * TASK_SECOND, TASK_FOREVER, &t10SCallback);
Task t60S   (TASK_MINUTE, TASK_FOREVER, &t60SCallback);
Task t600S  (10 * TASK_MINUTE, TASK_FOREVER, &t600SCallback);

Scheduler runner;

// *********** This is for the serial data parsing ******************
// Create a class for the serial data to be parsed
check_data   checkData;

// *********** This is for the data holders *************************
// Want to create a data class for each channel, up to max of NUM_CHANNELS
data_channel wind_speed_data;    // This creates our data channels

// *********** This is for the pulse counter ***********************
pulse_counter_ pulse_counter;

// *********** This is for the wind vane ***********************
wind_vane_array wind_vane_data;

// *********** These are global variables ***************************
String        inputString = "";           // a String to hold incoming data
String        errorString = "";           // a String to hold incoming data
String        returnString = "";          // A string to hold the returned data
bool          stringComplete = false;     // Checks if the string is complete
byte          UNIT_ID = B00000000;        // This is the unit_id of the board itself. This will be default value. Values from 0-255 can potentially be used. 4 bit binary number? = 16 channels.

uint32_t      led_flash_timer = millis();
bool          led_update_flag = true;
uint8_t       led_flash_counter = 0;        // Number of flashes to do
int           vane_training_direction = 0;    // This is used for the vane training mode

volatile int  data_counter_1s = 0;
volatile int  data_counter_10s = 0;
volatile int  data_counter_60s = 0;
volatile int  data_counter_600s = 0;
long int      debounce_time = millis();

void t1Callback() {
  // This loop runs every 100mS
  // This will record the value and store it

  // Check the wind vane
  // Need to convert the data into a direction in degrees (0-360)
  // This is then stored along with variation between the values (turbulance?)

  uint16_t vane_value = analogRead(VANE_PIN);
  wind_vane_data.data_1s_holder += vane_value;
  wind_vane_data.build_direction_array(vane_value);

  // It will then be averaged for 1s, 10s, 60s 10min and 1 hour averages
  data_counter_1s++;   // This counts the correct number of samples we take within the 1S sample period. Used for averaging.
}

void t1SCallback() {
  if (!t1S.isFirstIteration())
  {
    // ********* Sort out the wind speed ************************
    wind_speed_data.data_1s = (float) pulse_counter.pulse_counter_1;    // Store it here, in case it updates during this analysis
    pulse_counter.pulse_counter_1 = 0;      // reset the value

    // ******** Convert pulses into the wind speed here **********
    // wind_speed_data.data_1s - convert as a y=mx+c
    if (wind_speed_data.data_1s > 0)
    {
      wind_speed_data.data_1s = (wind_speed_data.data_1s * wind_speed_data.wind_speed_conv_m) + wind_speed_data.wind_speed_conv_c;
    }
    else
    {
      wind_speed_data.data_1s = 0;    // This stops the unit outputting 'c' when there are no pulses
      // no pulses is assumed to be zero wind speed (we cannot infer anything else)
    }

    // ***********************************************************
    // Here we set the max and min for the anemometer data
    if (wind_speed_data.data_1s < wind_speed_data.data_min)
    {
      wind_speed_data.data_min = wind_speed_data.data_1s;
    }
    if (wind_speed_data.data_1s > wind_speed_data.data_max)
    {
      wind_speed_data.data_max = wind_speed_data.data_1s;
    }
    // reset the data holder
    wind_speed_data.data_1s_holder  = 0;    // Reset the value
    wind_speed_data.data_10s_holder += wind_speed_data.data_1s; // Increment the 10s average

    //  ********** Sort out the Wind Vane ***********************************
    wind_vane_data.data_1s = wind_vane_data.data_1s_holder / data_counter_1s;
    wind_vane_data.data_1s_holder = 0;      // Reset the holder

    // Convert the direction_array into average number of seconds in each direction:
    for (int y = 0; y < 8; y++)
    {
      wind_vane_data.direction_array_values[y] += (float) wind_vane_data.direction_array[y] / (float) data_counter_1s;
      wind_vane_data.direction_array[y] = 0;
    }

    // If we are in Vane training mode then need to do different things here.
    // This flag is set in the serial parse:checkData pages
    if (checkData.vane_training_mode == true)
    {
      Serial.print(F("Training: \t"));
      // Want to convert the number 0-7 into direction N-NW)
      Serial.print(wind_vane_data.vane_directions[vane_training_direction]);
      Serial.print(F("\tValue: \t"));
      Serial.println(analogRead(VANE_PIN)); // Print the 1 second data for the wind vane
    }

    // Here we want to check if we are regularly sending the data and send if needed:
    if (wind_speed_data.send_wind_speed_data == 0 && checkData.vane_training_mode == false)
    {
      sendData(0);
      reset_data();
    }

    // Every second we recheck the bits of the UNIT_ID
    bitWrite(UNIT_ID, 0, !digitalRead(GPIO_ID0));
    bitWrite(UNIT_ID, 1, !digitalRead(GPIO_ID1));
    bitWrite(UNIT_ID, 2, !digitalRead(GPIO_ID2));

    display_wind_speed_data();

    // End of Display
    data_counter_10s ++;
    data_counter_1s = 0;   // Reset the counter
  }
}

void t10SCallback() {
  if (!t10S.isFirstIteration())
  {
    // 10 second averages
    wind_speed_data.data_10s = (float) wind_speed_data.data_10s_holder / (float) data_counter_10s;
    // reset all the data holders
    wind_speed_data.data_10s_holder  = 0;    // Reset the value
    // Add on values for next average
    wind_speed_data.data_60s_holder += wind_speed_data.data_10s;    // This is for the 60S averages

    // Here we want to check if we are regularly sending the data and send if needed:
    if (wind_speed_data.send_wind_speed_data == 1 && checkData.vane_training_mode == false)
    {
      sendData(1);
      reset_data();
    }
    data_counter_60s++;
    data_counter_10s = 0;
  }
}

void t60SCallback() {
  if (!t60S.isFirstIteration())
  {
    // 1 minute averages
    wind_speed_data.data_60s = (float)wind_speed_data.data_60s_holder / (float)data_counter_60s;
    // reset all the data holders
    wind_speed_data.data_60s_holder  = 0;
    // This is for the 600S averages
    wind_speed_data.data_600s_holder += wind_speed_data.data_60s;

    // Here we want to check if we are regularly sending the data and send if needed:
    if (wind_speed_data.send_wind_speed_data == 2 && checkData.vane_training_mode == false)
    {
      sendData(2);
      reset_data();
    }

    data_counter_600s++;
    data_counter_60s = 0;
  }
}

void t600SCallback() {
  // 10 minute averages
  if (!t600S.isFirstIteration())
  {
    wind_speed_data.data_600s = (float)wind_speed_data.data_600s_holder / (float)data_counter_600s;
    // reset all the data holders
    wind_speed_data.data_600s_holder  = 0;    // Reset the value

    // Here we want to check if we are regularly sending the data and send if needed:
    if (wind_speed_data.send_wind_speed_data == 3 && checkData.vane_training_mode == false)
    {
      sendData(3);
      reset_data();
    }

  }
  data_counter_600s = 0;
}


//ISR Functions for pulse counting
void ISR_PULSE_0()
{
  if ( millis() > debounce_time + DEBOUNCE_DELAY)
  {
    pulse_counter.pulse_counter_1++;    // Increment the counter
    debounce_time = millis();
  }
}

void tap(Button2 & btn)
{
  // In this routine we figure out which button has been pressed and deal with that:
  if (btn == buttonA)
  {
    if (checkData.vane_training_mode == true)
    {
      // If this is the case then the button just goes through the different directions
      // Want to store the vane_direction value into EEPROM at the correct location:

      // We store the 1 second average here:
      wind_vane_data.write_direction_array(vane_training_direction, analogRead(VANE_PIN) );

      // Then increment the counter (next direction)
      vane_training_direction++;

      if (vane_training_direction >= 8)
      {
        vane_training_direction = 0;
        checkData.vane_training_mode = false;
        // Need to figure out the bands again:
        wind_vane_data.read_direction_array();  // Gets data from EEPROM
        wind_vane_data.find_lower_bands(DEBUG_FLAG);
        wind_vane_data.find_upper_bands(DEBUG_FLAG);
        wind_vane_data.find_rollover_index(DEBUG_FLAG);

        // Want to reset the wind vane direction data as previous will be wrong!
        wind_vane_data.reset_vane_direction_array();
        Serial.println(F("Finished Training"));
      }
    }
    else
    {
      // If SWA pressed then increment the "send_wind_speed_data" from 0-1-2-3-4-5 and back to 0.
      // This means data will be shown at 1s/10s/60s/600s/3600s timescales.

      // In this case we start to send data at regular intervals.
      wind_speed_data.send_wind_speed_data++;
      if (wind_speed_data.send_wind_speed_data >= 6)
      {
        wind_speed_data.send_wind_speed_data = 0;
      }
      EEPROM.write(120, wind_speed_data.send_wind_speed_data);  // Update the EEPROM
      Serial.print(F("aaSEND"));
      Serial.print(wind_speed_data.send_wind_speed_data);
      Serial.println(END_STR);

      // Also want to flash the LED to show what send mode the unit is in:
      for (int i = 0; i < wind_speed_data.send_wind_speed_data; i++)
      {
        digitalWrite(LED0_PIN, true);
        delay(250);
        digitalWrite(LED0_PIN, false);
        delay(250);
      }
    }
  }
}
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
void loop()
{
  // Deal with schedules tasks
  runner.execute();
  // Check buttons for input
  buttonA.loop();
  // This flashes the LEDs as needed...
  flashLED();
  // feed the WDT
  wdt_reset();

  // Check for serial data
  if (stringComplete == true)
  {
    // This means we have had some data come in:
    // So parse it to find id and ave
    errorString = checkData.parseData(inputString, UNIT_ID, wind_speed_data);

    if (checkData.error_flag == true)
    {
      Serial.println(errorString);    // This needs to be returned
      checkData.error_flag = false;
    }
    else
    {
      if (checkData.baud_return_flag == true)
      {
        // Here we return the baud rate
        returnString = START_STR;
        returnString += (String)UNIT_ID;
        returnString += "BD";
        returnString += baud_rates[SERIAL_BAUD];
        returnString += END_STR;
        checkData.baud_return_flag = false;
        checkData.data_sent_flag = false;
      }
      else if (checkData.vane_data_flag == true)
      {
        returnString = START_STR;
        returnString += (String)UNIT_ID;
        returnString += "WV=";
        returnString += wind_vane_data.return_direction(analogRead(VANE_PIN)); // Print the instantaneous value of the wind vane as a direction

        for (int y = 0; y < 8; y++)
        {
          returnString += ":";
          returnString += (String)wind_vane_data.direction_array_values[y];
        }
        returnString += END_STR;
        checkData.vane_data_flag = false;
        checkData.data_sent_flag = false;
      }
      else if (checkData.conversion_return_flag == true)
      {
        // Return conversion settings "aaI0STWSCONm123.4c567.89#"
        returnString = START_STR;
        returnString += (String)UNIT_ID;
        returnString += "WVCONm";
        returnString += (String)wind_speed_data.wind_speed_conv_m;
        returnString += "c";
        returnString += (String)wind_speed_data.wind_speed_conv_c;
        returnString += END_STR;
        checkData.conversion_return_flag = false;
        checkData.data_sent_flag = false;
      }
      else if (checkData.conversion_set_flag == true)
      {
        // Return conversion settings "aaI0STWSCONm123.4c567.89#"
        wind_speed_data.wind_speed_conv_m = checkData.wind_speed_conv_m;
        wind_speed_data.wind_speed_conv_c = checkData.wind_speed_conv_c;
        // Store this data to EEPROM
        EEPROM.put(100, wind_speed_data.wind_speed_conv_m);
        EEPROM.put(110, wind_speed_data.wind_speed_conv_c);
        returnString = START_STR;
        returnString += (String)UNIT_ID;
        returnString += "WVSETm";
        returnString += (String)wind_speed_data.wind_speed_conv_m;
        returnString += "c";
        returnString += (String)wind_speed_data.wind_speed_conv_c;
        returnString += END_STR;
        checkData.conversion_set_flag = false;
        checkData.data_sent_flag = false;
      }
      else if (checkData.baud_set_flag == true)
      {
        Serial.end();
        // Here we set the baud rate to a new value and store in EEPROM
        returnString = START_STR;
        returnString += (String)UNIT_ID;
        returnString += "STBD";
        // Read the serial baud rate set in EEPROM
        SERIAL_BAUD = EEPROM.read(10);
        if (SERIAL_BAUD >= MAX_BAUD_RATES)
        {
          SERIAL_BAUD = 2;  // Initialise to 9600 if data out of range
        }
        // re-initialize serial communication:
        Serial.begin(baud_rates[SERIAL_BAUD]);
        returnString += baud_rates[SERIAL_BAUD];
        returnString += END_STR;
        checkData.baud_set_flag = false;
        checkData.data_sent_flag = false;
      }
      else if (checkData.data_sent_flag == true)
      {
        if (checkData.data_all_flag == true)
        {
          //******** RETURN ALL DATA FOR AVE *************************
          DEBUGLN(DEBUG_FLAG, "Return ALL DATA");
          returnString = START_STR;
          returnString += (String)UNIT_ID;
          returnString += "WSA" + (String)checkData.ave_time; // Initialise the returned string
          returnString += ":";
          for (int c = 0; c < 5; c++)
          {
            if (checkData.ave_time == c)
            {
              switch (c)
              {
                case 0:
                  returnString += (String)wind_speed_data.data_1s;
                  break;
                case 1:
                  returnString += (String)wind_speed_data.data_10s;
                  break;
                case 2:
                  returnString += (String)wind_speed_data.data_60s;
                  break;
                case 3:
                  returnString += (String)wind_speed_data.data_600s;
                  break;
              }
            }
          }
          returnString += ":";
          returnString += (String)wind_speed_data.data_max;
          returnString += ":";
          returnString += (String)wind_speed_data.data_min;
          returnString += END_STR;
          checkData.data_all_flag = false;
          checkData.data_sent_flag = false;
        }
        else if (checkData.data_min_flag == true)
        {
          //******** RETURN ALL MINIMUMS *************************
          DEBUGLN(DEBUG_FLAG, "Return ALL MINIMUMS");
          returnString = START_STR;
          returnString += (String)UNIT_ID;
          returnString += "WSMN"; // Initialise the returned string
          returnString += ":";
          returnString += (String)wind_speed_data.data_min;
          returnString += END_STR;
          checkData.data_min_flag = false;
          checkData.data_sent_flag = false;
        }
        else if (checkData.data_max_flag == true)
        {
          //******** RETURN ALL MAXIMUMS  *************************
          DEBUGLN(DEBUG_FLAG, "Return ALL MAXIMUMS");
          returnString = START_STR;
          returnString += (String)UNIT_ID;
          returnString += F("WSMX"); // Initialise the returned string
          returnString += ":";
          returnString += (String)wind_speed_data.data_max;
          returnString += END_STR;
          checkData.data_max_flag = false;
          checkData.data_sent_flag = false;
        }
      }
      else if (checkData.data_reset_flag == true)
      {
        // Want to reset the wind vane direction data as previous will be wrong!
        reset_data();
        returnString = F("aaRESET#");   // This needs to be returned
        checkData.data_reset_flag = false;
        checkData.data_sent_flag = false;
      }
      else if (checkData.send_wind_data_flag == true)
      {
        // In this case we start to send data at regular intervals.
        wind_speed_data.send_wind_speed_data = EEPROM.read(120);
        returnString = F("aaSENDOK#");   // This needs to be returned
        checkData.send_wind_data_flag = false;
        checkData.data_sent_flag = false;
      }
      else
      {
        returnString = FAIL_STR;
        checkData.data_sent_flag = false;
      }
      Serial.println(returnString);
    }
    inputString = "";
    stringComplete = false;
  }
}

/*
  SerialEvent occurs whenever a new data comes in the hardware serial RX. This
  routine is run between each time loop() runs, so using delay inside loop can
  delay response. Multiple bytes of data may be available.
*/
void serialEvent()
{
  while (Serial.available()) {
    // get the new byte:
    char inChar = (char)Serial.read();
    // add it to the inputString:
    inputString += inChar;
    // if the incoming character is a newline, set a flag so the main loop can
    // do something about it:
    if (inChar == '\n') {
      stringComplete = true;
    }
  }
}
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

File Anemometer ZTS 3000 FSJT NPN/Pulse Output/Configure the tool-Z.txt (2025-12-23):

Open this link to download the tools

Configure the tool to change the device address and baud rate:
https://drive.google.com/drive/folders/1fGTx7r_NDlRJPfm_LQPcdCKhRhXtE8Gl?usp=sharing

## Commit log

2021-07-16 Large initial commit. From SolarSensor
    [SolarSensorPCB-2021-06-18-14-28-08.sch, WindSensorPCB.kicad_pcb, WindSensorPCB.sch]
2021-07-19 Initial design for PCB and schematic
    [LM75TempSensor.sch, PhotoDiodeSensor.sch, PhotoDiodeSensorMCP3426.sch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]
2021-07-19 updated PCB
    [AC_to_Freq.sch, Hall_to_Freq.sch, LM75TempSensor.sch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]
2021-07-19 u[dated PCB
    [WindSensorATMEGA328_PCB.sch]
2021-07-19 Updated PCB
    Version 1 of the PCB with ATMEGA328 used...
    [Hall_to_Freq.sch, LM75TempSensor.sch, PhotoDiodeSensorMCP3426.sch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]
2021-10-17 large code update
    [Hall_to_Freq.sch, WInd_sensor_BOM_JLCPCB.csv, WindSensorATMEGA328_PCB.kicad_pcb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]
2021-10-17 updated to do correct vane direction
    [ATMega328_Wind_Sensor_Averaging.ino]
2021-10-21 Updated to work as wind sensor
    Added wind vane calculations
    Added wind speed calculations
    Added conversion store
    [WindSensorATMEGA328_PCB-B_Cu.gbr, WindSensorATMEGA328_PCB-B_Paste.gbr, WindSensorATMEGA328_PCB-B_SilkS.gbr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]
2021-10-22 Update ATMega328_Wind_Sensor_Averaging.ino
    Added correct reset
    Added set wind speed to zero if no pulses
    [ATMega328_Wind_Sensor_Averaging.ino]
2021-10-22 Create Wind Sensor Instructions.docx
    added instructions
2021-10-24 Updated code to act as broadcast
    [LM75TempSensor.sch, PhotoDiodeSensor.sch, PhotoDiodeSensorMCP3426.sch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]
2021-10-27 updated code with broadcast mode fix
    [WindSensorATMEGA328_PCB.kicad_pcb, WindSensorATMEGA328_PCB.sch]
2021-10-27 Update Wind Sensor Instructions.docx
2024-08-07 Update of PCB to add LPF on inputs
    [Hall_to_Freq.kicad_sch, WindSensorATMEGA328_PCB.kicad_pcb, WindSensorATMEGA328_PCB.kicad_sch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]
2024-10-30 Large update - firmware and PCB design. V2
    [Hall_to_Freq.kicad_sch, Hall_to_Freq.sch, WInd_sensor_BOM_JLCPCB.csv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]
2024-11-13 updated wind vane input
    [Wind_Vane.kicad_sch]
2024-11-20 Changed to 5V6 zener on all protection
    [Hall_to_Freq.kicad_sch, Wind_Vane.kicad_sch]
2024-11-20 updated instructions and schematic files
    [Hall_to_Freq.kicad_sch, WindSensorATMEGA328_PCB.kicad_pcb, Wind_Vane.kicad_sch]
2025-03-10 updated PCB for kicad 8
    [WindSensorATMEGA328_PCB.kicad_pcb]
2025-12-23 Small changes to main code
    Also added development folder for firmware to try to sort out no 'String' code version.
    [Configure the tool-Z.txt]
2026-03-13 removed firmware
    New firmware is in the sensor board interface so can be kept updated
2026-11-03 Update README.md
    added reset switch information
2026-11-03 Update README.md
    removed reset, user switch and led information (this is in firmware repository)
